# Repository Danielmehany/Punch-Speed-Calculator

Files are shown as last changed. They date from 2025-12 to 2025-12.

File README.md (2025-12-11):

# Punch Speed Calculator

**Test, measure, and compare your punch speed!**

A wearable device that measures punch speed in real-time. It uses an IMU to capture acceleration data, an STM32 microcontroller to compute velocity, and an OLED display to show results instantly.

Press start, raise your fist, and on the count of 3, punch!

<p align="center">
  
</p>

<p align="center">
  <a href="https://github.com/user-attachments/assets/401e8356-cbd4-48f5-857c-f3cd18cc75a6">📹 Watch Video Demo</a>
</p>

## Features

- **Real-time speed measurement** — Results displayed in km/h
- **Audible countdown** — 3-2-1 buzzer countdown before measurement
- **Compact wearable design** — Straps to your wrist
- **Battery powered** — Runs on a single AAA battery
- **1000 Hz sampling rate** — Captures acceleration every 1ms for accurate results

---

## PCB Design

The PCB was designed in **Altium Designer** and simulated in **LTspice**. The board integrates the IMU, OLED display, AAA battery holder, boost converter, buzzer, and STM32 Blackpill development board.

| Component | Description |
|---|---|
| MCU | STM32F411CEU6 (Blackpill) |
| IMU | MPU6050 (3-axis accelerometer/gyroscope) |
| Display | 128×64 OLED (I2C, SSD1306) |
| Power | AAA battery with 1.5V → 3.3V boost converter |
| Input | Tactile push button (start) |
| Audio | Piezo buzzer (countdown) |

<p align="center">
  
  
</p>

---

## Enclosure

The enclosure was designed in **SolidWorks** and 3D printed. It features PCB mounting posts, a protective barrier for components, and slots for a velcro wrist strap.

<p align="center">
  
  
</p>

---

## STM32 Firmware

The firmware is written in **C** using the **STM32 HAL** library in **STM32CubeIDE**.

### Program Flow

1. **Idle State** — Display shows "PRESS START" and waits for button press
2. **Countdown** — Buzzer sounds 3 times (250ms on, 500ms off) while display shows 3, 2, 1
3. **Data Capture** — IMU records X-axis acceleration every 1ms for 1 second (1000 samples)
4. **Processing** — Filters for positive acceleration values only (punch phase, excludes impact deceleration)
5. **Calculation** — Computes average acceleration and derives final velocity
6. **Display** — Shows punch speed in km/h for 5 seconds

### Speed Calculation

```
velocity = average_acceleration × gravity × time
speed (km/h) = velocity × 3.6
```

Where:
- `average_acceleration` = sum of positive samples ÷ count
- `gravity` = 9.81 m/s²
- `time` = count × 0.001s

### Typical Results

| Punch Type | Speed |
|---|---|
| Light jab | 10–20 km/h |
| Casual punch | 20–35 km/h |
| Hard punch | 35–50 km/h |
| Trained boxer | 50–80+ km/h |

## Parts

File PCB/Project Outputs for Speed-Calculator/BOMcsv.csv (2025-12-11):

Designator | Footprint | JLCPCB Part #
BOOST | MCHP-SOT-23-CHY6_N | C44365
BP1 | BAT-SMD_BH-AAA-B5BA021 | C7525446
BUZZER | BUZ-SMD_L9.6-W9.6-LS10.0-R | C96127
C1, C4 | CAPC1050X55X23ML05T13 | C1525
C2 | CAPC2013X75X45LL10T25 | C1710
C3 | FP-C2012-060-0_2-IPC_B | C28260
C5 | FP-CL31-IPC_C | C13585
C6 | FP-CL21-IPC_A | C1779
D1 | FP-403AE-MFG | C2480
DISP | OLED-TH_L27.8-W27.2-P2.54_C9900033791 | C5248080
IMU | IS-QFN-24_V | C24112
L1 | FP-LQM21PH_G0-IPC_C | C86090
Q1 | FP-SOT23-MFG | C20917
R1 | RESC1609X50X30ML8T20 | C22775
R2 | FP-CRCW0603-HPe3-IPC_C | C25803
R3, R4 | RESC1609X50X30NL10T20 | C4190
R5 | FP-AC0603-MFG | C48922
R6 | RESC1608X55X25NL10T15 | C185319
START | FP-PTS645SM43SMTR92LFS-MFG | C221880
STM32 | BLACK PILL V3

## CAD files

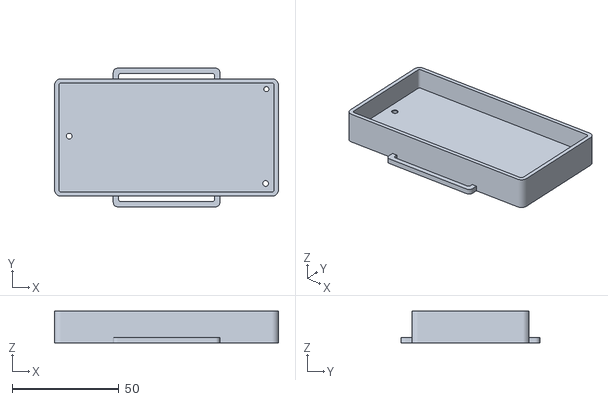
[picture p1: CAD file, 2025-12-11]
Mechanical Enclosure/PCB_Housing.STL
105.0 x 65.0 x 15.0

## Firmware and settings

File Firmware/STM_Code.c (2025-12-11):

#include "main.h"
#include "i2c.h"
#include "gpio.h"
#include <string.h>
#include <stdio.h>

typedef struct {
    char c;
    uint8_t col[5];
} FontChar;

// I2C Addresses
#define MPU6050_ADDR   (0x68 << 1)
#define OLED_ADDR      (0x3C << 1)

#define REG_PWR_MGMT_1   0x6B
#define REG_ACCEL_CONFIG 0x1C
#define REG_ACCEL_XOUT_H 0x3B

#define SAMPLE_COUNT      1000
#define SAMPLE_INTERVAL   1
#define GRAVITY           9.81f

#define OLED_WIDTH  128

static const FontChar font[] = {
    {'0', {0x3E,0x51,0x49,0x45,0x3E}},
    {'1', {0x00,0x42,0x7F,0x40,0x00}},
    {'2', {0x42,0x61,0x51,0x49,0x46}},
    {'3', {0x21,0x41,0x45,0x4B,0x31}},
    {'4', {0x18,0x14,0x12,0x7F,0x10}},
    {'5', {0x27,0x45,0x45,0x45,0x39}},
    {'6', {0x3C,0x4A,0x49,0x49,0x30}},
    {'7', {0x01,0x71,0x09,0x05,0x03}},
    {'8', {0x36,0x49,0x49,0x49,0x36}},
    {'9', {0x06,0x49,0x49,0x29,0x1E}},
    {' ', {0x00,0x00,0x00,0x00,0x00}},
    {'.', {0x00,0x60,0x60,0x00,0x00}},
    {'-', {0x08,0x08,0x08,0x08,0x08}},
    {'/', {0x20,0x10,0x08,0x04,0x02}},
    {'A', {0x7E,0x09,0x09,0x09,0x7E}},
    {'B', {0x7F,0x49,0x49,0x49,0x36}},
    {'C', {0x3E,0x41,0x41,0x41,0x22}},
    {'D', {0x7F,0x41,0x41,0x41,0x3E}},
    {'E', {0x7F,0x49,0x49,0x49,0x41}},
    {'F', {0x7F,0x09,0x09,0x09,0x01}},
    {'G', {0x3E,0x41,0x49,0x49,0x7A}},
    {'H', {0x7F,0x08,0x08,0x08,0x7F}},
    {'I', {0x00,0x41,0x7F,0x41,0x00}},
    {'K', {0x7F,0x08,0x14,0x22,0x41}},
    {'L', {0x7F,0x40,0x40,0x40,0x40}},
    {'M', {0x7F,0x02,0x0C,0x02,0x7F}},
    {'N', {0x7F,0x04,0x08,0x10,0x7F}},
    {'O', {0x3E,0x41,0x41,0x41,0x3E}},
    {'P', {0x7F,0x09,0x09,0x09,0x06}},
    {'R', {0x7F,0x09,0x19,0x29,0x46}},
    {'S', {0x46,0x49,0x49,0x49,0x31}},
    {'T', {0x01,0x01,0x7F,0x01,0x01}},
    {'U', {0x3F,0x40,0x40,0x40,0x3F}},
    {'Y', {0x07,0x08,0x70,0x08,0x07}},
    {'a', {0x20,0x54,0x54,0x54,0x78}},
    {'b', {0x7F,0x48,0x44,0x44,0x38}},
    {'c', {0x38,0x44,0x44,0x44,0x20}},
    {'d', {0x38,0x44,0x44,0x48,0x7F}},
    {'e', {0x38,0x54,0x54,0x54,0x18}},
    {'h', {0x7F,0x08,0x04,0x04,0x78}},
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
};
#define FONT_SIZE (sizeof(font)/sizeof(font[0]))

char textBuf[32];
float samples[SAMPLE_COUNT];

void SystemClock_Config(void);

void OLED_Command(uint8_t cmd);
void OLED_Data(uint8_t *data, uint16_t size);
void OLED_Init(void);
void OLED_Clear(void);
void OLED_SetCursor(uint8_t col, uint8_t page);
void OLED_WriteChar(uint8_t col, uint8_t page, char c);
void OLED_WriteChar2X(uint8_t col, uint8_t page, char c);
void OLED_Print(uint8_t col, uint8_t page, char *str);
void OLED_PrintCentered(uint8_t page, char *str);
void OLED_PrintCentered2X(uint8_t page, char *str);

int main(void)
{
 
  HAL_Init();

  SystemClock_Config();

  MX_GPIO_Init();
  MX_I2C1_Init();

  HAL_Delay(100);

  // Wake up MPU6050 (try multiple times)
  uint8_t data[2];
  for (int attempt = 0; attempt < 3; attempt++)
  {
      data[0] = REG_PWR_MGMT_1;
      data[1] = 0x00;
      if (HAL_I2C_Master_Transmit(&hi2c1, MPU6050_ADDR, data, 2, 100) == HAL_OK)
          break;
      HAL_Delay(50);
  }
  HAL_Delay(50);

  // Set MPU6050 to ±16g range
  data[0] = REG_ACCEL_CONFIG;
  data[1] = 0x18;
  HAL_I2C_Master_Transmit(&hi2c1, MPU6050_ADDR, data, 2, 100);
  HAL_Delay(10);

  // Initialize OLED
  OLED_Init();
  OLED_Clear();

  // Show idle screen
  OLED_PrintCentered2X(0, "PRESS");
  OLED_PrintCentered2X(2, "START");
  OLED_PrintCentered(5, "Punch on 3rd buzz!");

  while (1)
  {
    // Wait for button press (PA1, active low)
    if (HAL_GPIO_ReadPin(GPIOA, GPIO_PIN_1) == GPIO_PIN_RESET)
    {
        HAL_Delay(50);
        if (HAL_GPIO_ReadPin(GPIOA, GPIO_PIN_1) != GPIO_PIN_RESET) continue;

        // ========== COUNTDOWN ==========

        // Buzz 1
        OLED_Clear();
        OLED_PrintCentered2X(2, "3");
        HAL_GPIO_WritePin(GPIOA, GPIO_PIN_4, GPIO_PIN_SET);
        HAL_Delay(250);
        HAL_GPIO_WritePin(GPIOA, GPIO_PIN_4, GPIO_PIN_RESET);
        HAL_Delay(500);

        // Buzz 2
        OLED_Clear();
        OLED_PrintCentered2X(2, "2");
        HAL_GPIO_WritePin(GPIOA, GPIO_PIN_4, GPIO_PIN_SET);
        HAL_Delay(250);
        HAL_GPIO_WritePin(GPIOA, GPIO_PIN_4, GPIO_PIN_RESET);
        HAL_Delay(500);

        // Buzz 3
        OLED_Clear();
        OLED_PrintCentered2X(2, "1");
        HAL_GPIO_WritePin(GPIOA, GPIO_PIN_4, GPIO_PIN_SET);
        HAL_Delay(250);
        HAL_GPIO_WritePin(GPIOA, GPIO_PIN_4, GPIO_PIN_RESET);

        // ========== CAPTURE SAMPLES ==========

        OLED_Clear();
        OLED_PrintCentered2X(2, "GO!");

        uint32_t nextSampleTime = HAL_GetTick();

        for (int i = 0; i < SAMPLE_COUNT; i++)
        {
            while (HAL_GetTick() < nextSampleTime) {}

            // Read X acceleration
            uint8_t reg = REG_ACCEL_XOUT_H;
            uint8_t buf[2];
            HAL_I2C_Master_Transmit(&hi2c1, MPU6050_ADDR, &reg, 1, HAL_MAX_DELAY);
            HAL_I2C_Master_Receive(&hi2c1, MPU6050_ADDR, buf, 2, HAL_MAX_DELAY);

            int16_t rawX = (int16_t)((buf[0] << 8) | buf[1]);
            samples[i] = -((float)rawX / 2048.0f);  // Flip sign, convert to g

            nextSampleTime += SAMPLE_INTERVAL;
        }

        // ========== CALCULATE SPEED ==========

        // Only use positive acceleration values
        float sumAccel = 0.0f;
        int count = 0;

        for (int i = 0; i < SAMPLE_COUNT; i++)
        {
            if (samples[i] > 0)
            {
                sumAccel += samples[i];
                count++;
            }
        }

        // Calculate velocity
        float speedKmh = 0.0f;
        if (count > 0)
        {
            float avgAccel = sumAccel / count;
            float totalTime = count * 0.001f;
            float velocity = avgAccel * GRAVITY * totalTime;
            speedKmh = velocity * 3.6f;
        }

        // ========== DISPLAY RESULT ==========

        OLED_Clear();
        OLED_PrintCentered(0, "Punch Speed");

        int speedInt = (int)speedKmh;
        int speedDec = (int)((speedKmh - speedInt) * 10);
        if (speedDec < 0) speedDec = -speedDec;
        snprintf(textBuf, sizeof(textBuf), "%d.%d", speedInt, speedDec);
        OLED_PrintCentered2X(2, textBuf);

        OLED_PrintCentered2X(5, "km/h");

        HAL_Delay(5000);

        // ========== BACK TO IDLE ==========

        OLED_Clear();
        OLED_PrintCentered2X(0, "PRESS");
        OLED_PrintCentered2X(2, "START");
        OLED_PrintCentered(5, "Punch on 3rd buzz!");

        while (HAL_GPIO_ReadPin(GPIOA, GPIO_PIN_1) == GPIO_PIN_RESET)
        {
            HAL_Delay(10);
        }
    }

    HAL_Delay(20);
  }
}

void SystemClock_Config(void)
{
  RCC_OscInitTypeDef RCC_OscInitStruct = {0};
  RCC_ClkInitTypeDef RCC_ClkInitStruct = {0};

  __HAL_RCC_PWR_CLK_ENABLE();
  __HAL_PWR_VOLTAGESCALING_CONFIG(PWR_REGULATOR_VOLTAGE_SCALE1);

  RCC_OscInitStruct.OscillatorType = RCC_OSCILLATORTYPE_HSI;
  RCC_OscInitStruct.HSIState = RCC_HSI_ON;
  RCC_OscInitStruct.HSICalibrationValue = RCC_HSICALIBRATION_DEFAULT;
  RCC_OscInitStruct.PLL.PLLState = RCC_PLL_NONE;
  if (HAL_RCC_OscConfig(&RCC_OscInitStruct) != HAL_OK)
  {
    Error_Handler();
  }

  RCC_ClkInitStruct.ClockType = RCC_CLOCKTYPE_HCLK|RCC_CLOCKTYPE_SYSCLK
                              |RCC_CLOCKTYPE_PCLK1|RCC_CLOCKTYPE_PCLK2;
  RCC_ClkInitStruct.SYSCLKSource = RCC_SYSCLKSOURCE_HSI;
  RCC_ClkInitStruct.AHBCLKDivider = RCC_SYSCLK_DIV1;
  RCC_ClkInitStruct.APB1CLKDivider = RCC_HCLK_DIV1;
  RCC_ClkInitStruct.APB2CLKDivider = RCC_HCLK_DIV1;

  if (HAL_RCC_ClockConfig(&RCC_ClkInitStruct, FLASH_LATENCY_0) != HAL_OK)
  {
    Error_Handler();
  }
}

// =================== OLED FUNCTIONS ===================

void OLED_Command(uint8_t cmd)
{
    uint8_t data[2] = {0x00, cmd};
    HAL_I2C_Master_Transmit(&hi2c1, OLED_ADDR, data, 2, HAL_MAX_DELAY);
}

void OLED_Data(uint8_t *data, uint16_t size)
{
    uint8_t buffer[17];
    buffer[0] = 0x40;
    while (size > 0)
    {
        uint8_t chunk = (size > 16) ? 16 : size;
        memcpy(&buffer[1], data, chunk);
        HAL_I2C_Master_Transmit(&hi2c1, OLED_ADDR, buffer, chunk + 1, HAL_MAX_DELAY);
        data += chunk;
        size -= chunk;
    }
}

void OLED_Init(void)
{
    HAL_Delay(100);
    OLED_Command(0xAE);  // Display off
    OLED_Command(0x20); OLED_Command(0x00);  // Horizontal addressing
    OLED_Command(0xB0);  // Page 0
    OLED_Command(0xC8);  // COM scan direction
    OLED_Command(0x00); OLED_Command(0x10);  // Column 0
    OLED_Command(0x40);  // Start line 0
    OLED_Command(0x81); OLED_Command(0xFF);  // Max contrast
    OLED_Command(0xA1);  // Segment remap
    OLED_Command(0xA6);  // Normal display
    OLED_Command(0xA8); OLED_Command(0x3F);  // Multiplex 64
    OLED_Command(0xA4);  // Display from RAM
    OLED_Command(0xD3); OLED_Command(0x00);  // No offset
    OLED_Command(0xD5); OLED_Command(0x80);  // Clock
    OLED_Command(0xD9); OLED_Command(0xF1);  // Pre-charge
    OLED_Command(0xDA); OLED_Command(0x12);  // COM pins
    OLED_Command(0xDB); OLED_Command(0x40);  // VCOMH
    OLED_Command(0x8D); OLED_Command(0x14);  // Charge pump on
    OLED_Command(0xAF);  // Display on
}

void OLED_SetCursor(uint8_t col, uint8_t page)
{
    OLED_Command(0xB0 | (page & 0x07));
    OLED_Command(0x00 | (col & 0x0F));
    OLED_Command(0x10 | ((col >> 4) & 0x0F));
}

void OLED_Clear(void)
{
    uint8_t zeros[128] = {0};
    for (uint8_t page = 0; page < 8; page++)
    {
        OLED_SetCursor(0, page);
        OLED_Data(zeros, 128);
    }
}

void OLED_WriteChar(uint8_t col, uint8_t page, char c)
{
    uint8_t buf[6] = {0, 0, 0, 0, 0, 0};

    for (int i = 0; i < FONT_SIZE; i++)
    {
        if (font[i].c == c)
        {
            for (int j = 0; j < 5; j++) buf[j] = font[i].col[j];
            break;
        }
    }

    OLED_SetCursor(col, page);
    OLED_Data(buf, 6);
}

void OLED_WriteChar2X(uint8_t col, uint8_t page, char c)
{
    uint8_t bufTop[12] = {0};
    uint8_t bufBot[12] = {0};

    // Find character in font
    const uint8_t *cols = NULL;
    for (int i = 0; i < FONT_SIZE; i++)
    {
        if (font[i].c == c)
        {
            cols = font[i].col;
            break;
        }
    }
    if (cols == NULL) return;

    // Scale 2x vertically and horizontally
    for (int i = 0; i < 5; i++)
    {
        uint16_t scaled = 0;
        for (int bit = 0; bit < 8; bit++)
        {
            if (cols[i] & (1 << bit))
                scaled |= (3 << (bit * 2));
        }
        bufTop[i*2] = bufTop[i*2+1] = scaled & 0xFF;
        bufBot[i*2] = bufBot[i*2+1] = (scaled >> 8) & 0xFF;
    }

    OLED_SetCursor(col, page);
    OLED_Data(bufTop, 12);
    OLED_SetCursor(col, page + 1);
    OLED_Data(bufBot, 12);
}

void OLED_Print(uint8_t col, uint8_t page, char *str)
{
    while (*str)
    {
        OLED_WriteChar(col, page, *str++);
        col += 6;
        if (col > 122) break;
    }
}

void OLED_PrintCentered(uint8_t page, char *str)
{
    uint8_t len = strlen(str);
    uint8_t col = (OLED_WIDTH - len * 6) / 2;
    OLED_Print(col, page, str);
}

void OLED_PrintCentered2X(uint8_t page, char *str)
{
    uint8_t len = strlen(str);
    uint8_t col = (OLED_WIDTH - len * 12) / 2;
    while (*str)
    {
        OLED_WriteChar2X(col, page, *str++);
        col += 12;
        if (col > 116) break;
    }
}

/* USER CODE END 4 */

void Error_Handler(void)
{
  __disable_irq();
  while (1) {}
}

#ifdef USE_FULL_ASSERT
void assert_failed(uint8_t *file, uint32_t line)
{
  (void)file;
  (void)line;
}
#endif
